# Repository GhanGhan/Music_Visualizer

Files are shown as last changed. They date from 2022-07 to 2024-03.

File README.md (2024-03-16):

# Overview      
The device receives an audio signal from a 3.5mm jack (i.e. a headphone jack) that is connected to any analog sound source. The audio signal is then separated into the **7 music frequency ranges** and their respective volumes' are then **displayed on 10 LED's using a decibel scale.**
The brightness of the LEDs and the maximum value of the decibal scale can be adjusted by the user by turning the potentiometers located at the bottom of the PCB shown in *Figure 1*!

Full_3D_View
***Figure 1: 3D View***
<!---
Hello world

<figure>
   <img src="https://github.com/GhanGhan/Music_Visualizer/assets/17633599/c1a8e4e7-99a0-4a1e-9c01-7bc1968a0fe4">
   <figcaption>**Figure 1: 3D View of Music Visualizer**</figcaption>
</figure>
--->

# Table of Contents
1. Summary of Functionaity
2. Operation Videos
3. Contained in Respository
4. Repository Structure
5. Folder & Design File Explanation
6. Generate Files for Fabrication
7. Current Issues
8. License
9. Acknowledgements

# Summary of Functionality
- Can change input source to a male or female jack using a slide switch as shown in *Figure 2*
- Can safely handle a differential input voltage signal of up to 32V
- Uses 6th order 60dB/decade active Butterworth filters to segment the signal into 7 spectrums
- Both the brightness of the LEDs and maximum scale voltage can be changed using logarithmic potentiometers
   - ** Due to how signal is processed by the filters, the maximum value of the volume scale is 3.5V
- 10 LEDS are used to display the volume of each spectrum as a percentage of the max value of the volume scale
   - 4 Blue LEDs     [4% : 12%]
   - 3 Yellow LEDS   [12% : 35%]
   - 3 Red LEDS      [35% : 100%]
Block Diagaram
***Figure 2: Block Diagaram of Signal, Power and Control Flow***

# Contained in Repository
- Spice design files (made using LTSpice)
- Schematic Capture and PCB layout (designed in KiCAD)
- Bill-of-Materials BOM
- Other important documents:
   - Sound characterization
   - Measured Frequency response
   - Docs related to properties of critical electrical components

# Operation Videos
Frequency_Sweep_Thumb25 (https://www.youtube.com/watch?v=qO5JhvR4XTk)
Capabilities_Thumb25 (https://www.youtube.com/watch?v=kU3bXjiCjgI)
Visualization_Thumb25 (https://www.youtube.com/watch?v=t0gG-SFj2FQ)

# Repository Structure
```
├── Documents
│   ├── BOM_Final.xlsx
│   ├── LED Driver IC.xlsx
│   ├── MaxIoOfEachFilterStage.xlsx
│   ├── Measured_Frequency_Response.xlsx
│   ├── Sound_Characterization.xlsx
│   └── Trace width vs current.xlsx
├── Schematic_PCB/Music_Visualizer
│   ├── Music_Visualizer-backups
│   ├── Project Library
│   │   ├── Coloured_LEDs
│   │   │   ├── LED D5 - Blue_cutted.step
│   │   │   ├── LED D5 - Red_cutted.step
│   │   │   └── LED D5 - Yellow_cutted.step
│   │   ├── DC_Power_Jack
│   │   │   ├── CUI_DEVICES_PJ-079BH.step
│   │   │   ├── CUI_DEVICES.kicad_mod
│   │   │   └── PJ-079BH.lib
│   │   ├── Female_Audio_Jack
│   │   │   └── SJ-3523-SMT-TR--3DModel-STEP-56544.step
│   │   ├── LM3915_LED_Driver
│   │   │   └── LM3915N-1.lib
│   │   ├── Linear_Voltage_Regulator
│   │   │   ├── DIP794W45P254L959H508Q8.kicad_mod
│   │   │   └── LT1054IPE4.step
│   │   ├── PTV09A_Pot_Vertical
│   │   │   ├── PTV09.kicad_mod
│   │   │   └── PTV09A-4225F-B104.step
│   │   ├── PW_On_Off_Switch
│   │   │   ├── E-SWITCH_RR511D1121.kicad_mod
│   │   │   └── RR511D1121.step
│   │   ├── Slide_Switch
│   │   │   ├── OS102011MS2QN1.step
│   │   │   └── SW_OS102011MS2QN1.kicad_mod
│   │   ├── License.txt
│   │   └── how-to-import.htm
│   ├── Music_Visualizer.csv
│   ├── Music_Visualizer.kicad_pcb
│   ├── Music_Visualizer.kicad_prl
│   ├── Music_Visualizer.kicad_pro
│   ├── Music_Visualizer.kicad_sch
│   ├── Music_Visualizer.wbk
│   ├── Music_Visualizer.xml
│   ├── Power.kicad_sch
│   ├── fp-info-cache
│   ├── fp-lib-table
│   └── sym-lib-table
└── Simulated Circuits
    ├── Entire_Circuit 
    │   ├── Full_Visualizer.asc
    │   └── LM324.txt
    ├── Filters_With_LED_Drivers
    │   ├── FinalBassFilterWithLEDDriver.asc
    │   ├── FinalBrillianceFilterWithLEDDriver.asc
    │   ├── FinalLowMidrangeWithLEDDriver.asc
    │   ├── FinalMidrangeFilterWithLEDDriver.asc
    │   ├── FinalPresenceFilterWithLEDDriver.asc
    │   ├── FinalSubBassFilterWithLEDDriver.asc
    │   ├── FinalUpperMidrangeFilterWithLEDDriver.asc
    │   └── LM324.txt
    ├── LED_Driving
    │   ├── LM3915_Base_Circuit.asc
    │   ├── LM3915_Chain.asc
    │   ├── RhiControl_LTC1250.asc
    │   └── Voltage_Follower_Replacement.asc
    ├── Power
    │   ├── LT1054_Inverter_and_regulator.asc
    │   └── Reverse_Voltage_Protection.asc
    └── Spectrum_Filters
        ├── Final_Filters
        │   ├── FinalBassFilterBuf.asc
        │   ├── FinalBrillianceFilterBuf.asc
        │   ├── FinalLowMidrangeBuf.asc
        │   ├── FinalMidrangeFilterBuf.asc
        │   ├── FinalPresenceFilterBuf.asc
        │   ├── FinalSubBassFilterBuf.asc
        │   ├── FinalUpperMidrangeFilterBuf.asc
        │   └── LM324.txt
        ├── Ideal_Filters
        │   ├── BassFilterSK.asc
        │   ├── BrillianceFilterSK.asc
        │   ├── LowMidrangeSK.asc
        │   ├── MidrangeFilterSK.asc
        │   ├── PresenceFilterSK.asc
        │   ├── SubBassFilterSK.asc
        │   └── UpperMidrangeFilterSK.asc
        └── JsonFiles
            ├── Bass Filter.asc
            ├── Brilliance Filter.asc
            ├── Low-Midrange.asc
            ├── Midrange Filter.asc
            ├── Presence Filter.asc
            ├── Sub-Bass Filter.asc
            └── Upper-MidrangeFilter.asc
  ```
# Folder & Design File Explanation
## Documents
- **BOM_Final:** The project Bill-Of-Materials (BOM)
   - Shows all the components that were used, the quantity of each, the prices, model number and where they were sourced from
- **LED Driver IC:** Comparison of the simulated characteristics and values found from breadboarding
- **MaxIoOfEachFilterStage:** Maximum possible current being output by each op-amp of each stage of every filter
- **Sound Characterization:** Shows voltages that were outputted from the audio jack the device was tested on, bandwidth and corner frequency of each spectrum, and steps of the volume-meter
## Schematic_PCB\Music Visualizer (KiCad Folder)
- **Project_Library:** Contains nesseccary .step files (3D models), .lib files (schematic symbols) and/or .kicad_mod files (PCB footprint)  of the DC power jack, female audio jack, LED driver, -5V Inverter & Regulator, potentiometer, On/Off rocker switch switch and slide switch.
    - If any of the file types for any of the circuit elements is not included in the associated sub-folder of the 'Project Library then it is provided by the programs 'Global Library'.
- **Music_Visualizer.kicad_pcb:** PCB layout file for the entire project.
- **Music_Visualizer.kicad_sch:** Main schematic layout file.
    - Contains all 7 frequency spectrums based on the spice files in Simulated_Circuits\Spectrum_Filter\Final_Filter folder.
    - Contains the Audio input circuit (male and female connections where a slide switch is used to choose one or the other), the mounting holes, and op amp bypass capacitors.
    - Contains the Power.kicad_sch and LED_driver.kicad_sch schematics as well
    - **Power.kicad_sch:** Contians circuit for the the +5V regulator, circuit to connect to external power supply with with reverse voltage protection  and -5V Inverter/Regulator as shown in *Figure 3*, the latter 2 are based on the spice files in Simulatd_Circuits\Power.
Power_Circuitry
***Figure 3: 9V & +/-5V Power Circuitry***

    - **Led_Driver.kicad_sch:** Contains the 7 LED drivers, LED brightness control and Rhi-Value Control Circuit based on the spice files in LED_Driving folder.
- **Music_Visualizer.kicad_pro:** Music Visualizer KiCad File.  When clicked it opens up a directory that allows you to access the PCB layout file and schematic layout file.
- Rest of the files are either self explanatory of support files for the KiCad program
## Simulated_Circuits
- **Entire Circuit\Full_Visualizer.asc:** A spice file that contains the 7 spectrum filters being driven by the input signal that contains a frequency from each of the spectrums.  Each of the filters is driving one of the ICs in the LM3915_Chain circuit.  Voltage dividers are used in place of potentiometers to model how turning their knobs allows for control of the LED brightness and scale of the volumeter.
    - **LM324.txt:** A text file that contains the 'macromodel' of the LM324 operational amplifier, allowing it to be used in spice files
- **Filters_With_LED_Drivers:** Contains a spice file for every spectrum filter that driving an LM3915_Base_Circuit.  Also contains an LM324.txt file.
- **LED_Driving:**
    - **LM3915_Base_Circuit.asc:** Contains an LM3915 (the led driver) IC connected to 10 LEDs as shown in *Figure 4*.  The IC is driven by a sinusoidal voltage source.  **Vref (Current reference pin)** is used to set the diode current to about 18mA using a grounded 674 ohm resistor.  It is powered by 9V, and **Vrhi (high-input reference-voltage)** is set to 3.5V.
Base_DriverV2
***Figure 4: LED Driving Circuit Prototype***

    - **LM3915_Chain.asc:** Contains 7 LM3915_Base circuits all driven by the same input AC voltage and high-input reference voltage.  Instead of ground, the 674 ohm resistor of each LM3915_Base circuit is connected to a grounded 10kohm potentiometer.  Changing the resistance of the potentiometer allows one to adjust the current going through the LEDs of all of the LED drivers.
    - **RhiControl_LTC1250.asc:** Connects to the high-input reference voltage pin (*Rhi in Figure 4*) of the LED driver IC as shown in *Figure 5*.  R1 and R2 act as a potentiometer. A voltage follower is appended to the ouput of the 'potentiometer' because the average load voltage of the Vrhi pin is about 17.5kohm, when there are in parallel the equivalent reisistance is about 2.5kohm.  The voltage follower ensures that the voltage at the pins is is the same value as the output of the potentiometer.  This particular op-amp was chosen because it has a max input offset voltage of < |10uV|, this means that the voltage at the pin will always be within 10uV of the desired voltage.
RhiControl_LTC1250_Enlarged
***Figure 5: Volume Scale Range Control Circuit***
  
    - **Voltage_Follower_Replacement.asc:**  This is a common-collector circuit, a single transistor implementation of a current follower.  The 2N2222 transistor is used to replace the LTC1250 op-amp because it shorted the -5 and +5 terminals that it was being powered from.
- **Spectrum_Filters:**
    - **Final_Filters:** Folder contains the final filter design for the 7 spectrum filters; Sub-Bass, Bass, Low-Midrange, Midrange, Upper-Midrange, Presence and Brilliance.  Each filter is prepended with a voltage buffer to isolate themselves from the signal source.  This way the impedances of the filters do not affect each other.  Each filter also has a high-pass filter appended to it to prevent unintented activation of the LED driver due to the input-offset voltage of the LM324 op amps which can be as high as 7mV.  *Figure 6* displays the Sub-Bass filters, all of the spectrum filters have the same topology.
  SubBaseFinalFilter
***Figure 6: Complete Sub-Base Filter**

         - Also the resistor values in the final design are slightly different from the "ideal version".  This is because those resistances need at least two resistors in series or parallel to be realized.  The nominal resistor values choses for the final design are within 1.5% of the ideal value.  It was determined that this did not have a significant effect on the frequency response. 
    - **Ideal_Filters:** Folder contains design for idealized implementation of the 7 spectrum filters.  In these LTSpice files ideal op-amps are being used and all of the resistor values match the values provided from the Analog Filter Wizard.
    - **JsonFiles:** The spectrum filters were designed using Analog Devices 'Analog Filter Wizard'.  Once you've inputted the specifications "Passband gain, corner frequency, bandwidth, stopband, center frequency, stages etc."  These are the saved specification files of the Analog filter Wizard for each filter.
         - The center frequency saved in these files are different from the actual center frequency of the filters because (for unidentified reasons) when the correct center frequency was inputted to wrong corner frequencies were outputed.  The center frequency contained in these files gives filters with the correct corner frequencies.

# Generate Files for Fabrication
- If you want to generate the Gerber and Drill files so that the project can be fabricated by a JLCPCB, follow the steps of this website: https://jlcpcb.com/help/article/16-How-to-generate-Gerber-and-Drill-files-in-KiCad-6

# Current Issues
- The last stage of the sub-bass filter generates a power 343Hz wave on its own that is so powerful it activates all of the associated LEDS.  
- The LT1054 op amp shorts the +5 and -5 power rails together and destroys itself in the process.  The is why it was replaced with a Common Collector circuit.

# License
- 
- This project is licensed under the [Creative Commons Attribution 3.0 Unported License](https://creativecommons.org/licenses/by/3.0/).
  
# Acknoledgments
- I would like to thank Snap EDA for providing me with the necessary step, kicad_mod and lib files.
- I would like to thank the YouTube Channel "Phil's Lab" for making videos that allowed me to easily learn to use KiCad 6.

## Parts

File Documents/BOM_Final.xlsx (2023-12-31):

Comment | Designator | Footprint | Quantity | Digi-Key PN | MPN | Price | Total Price | Part Page
47n | C1,C2 | Capacitor_SMD:C_0603_1608Metric_Pad1.08x0.95mm_HandSolder | 2 | 1292-1445-1-ND | 0603B473J250CT | $0.10 | $0.20 | https://www.digikey.ca/en/products/detail/walsin-technology-corporation/0603B473J250CT/9354942
24n | C11,C12 | Capacitor_SMD:C_0805_2012Metric | 2 | 478-10432-1-ND | 08051C243JAT2A | $0.43 | $0.86 | https://www.digikey.ca/en/products/detail/kyocera-avx/08051C243JAT2A/1601378
4.7n | C13,C14 | Capacitor_SMD:C_0603_1608Metric_Pad1.08x0.95mm_HandSolder | 2 | 1292-1440-1-ND | 0603B472J500CT | $0.10 | $0.20 | https://www.digikey.ca/en/products/detail/walsin-technology-corporation/0603B472J500CT/9354937
3.3n | C15,C16 | Capacitor_SMD:C_0603_1608Metric_Pad1.08x0.95mm_HandSolder | 2 | 1292-1521-1-ND | 0603N332J500CT | $0.10 | $0.20 | https://www.digikey.ca/en/products/detail/walsin-technology-corporation/0603N332J500CT/9355018
6.2n | C17,C18 | Capacitor_SMD:C_0805_2012Metric | 2 | 490-1637-1-ND | GRM2195C1H622JA01D | $0.41 | $0.82 | https://www.digikey.ca/en/products/detail/murata-electronics/GRM2195C1H622JA01D/586784
1.6n | C19,C20 | Capacitor_SMD:C_0603_1608Metric_Pad1.08x0.95mm_HandSolder | 2 | 490-1456-1-ND | GRM1885C1H162JA01D | $0.18 | $0.36 | https://www.digikey.ca/en/products/detail/murata-electronics/GRM1885C1H162JA01D/586948
1n | C21,C22,C25,C26,C27,C28,C29,C30,C31,C32,C33,C34,C35,C36,C37,C38,C41,C42 | Capacitor_SMD:C_0603_1608Metric_Pad1.08x0.95mm_HandSolder | 18 | 1276-1091-1-ND | CL10C102JB8NNNC | $0.10 | $1.80 | https://www.digikey.ca/en/products/detail/samsung-electro-mechanics/CL10C102JB8NNNC/3886749
3n | C23,C24 | Capacitor_SMD:C_0603_1608Metric_Pad1.08x0.95mm_HandSolder | 2 | 490-6384-1-ND | GRM1885C1H302JA01D | $0.11 | $0.22 | https://www.digikey.ca/en/products/detail/murata-electronics/GRM1885C1H302JA01D/2611152
27n | C3,C4 | Capacitor_SMD:C_0603_1608Metric_Pad1.08x0.95mm_HandSolder | 2 | 478-KAF15AR71H273JMTR-ND | KAF15AR71H273JM | $0.18 | $0.36 | https://www.digikey.ca/en/products/detail/kyocera-avx/KAF15AR71H273JM/3660870
820p | C39,C40 | Capacitor_SMD:C_0603_1608Metric_Pad1.08x0.95mm_HandSolder | 2 | 1292-1548-1-ND | 0603N821J500CT | $0.14 | $0.28 | https://www.digikey.ca/en/products/detail/walsin-technology-corporation/0603N821J500CT/9355045
100u | C43,C44 | Capacitor_SMD:C_1206_3216Metric | 2 | 490-GRM31CD80J107MEA8KCT-ND | GRM31CD80J107MEA8K | $0.56 | $1.12 | https://www.digikey.ca/en/products/detail/murata-electronics/GRM31CD80J107MEA8K/13905021
10u | C45,C46,C54 | Capacitor_SMD:C_0805_2012Metric | 3 | 1276-1096-1-ND | CL21A106KOQNNNE | $0.14 | $0.42 | https://www.digikey.ca/en/products/detail/samsung-electro-mechanics/CL21A106KOQNNNE/3886754
1u | C47,C48,C49,C52,C53,C57,C58 | Capacitor_SMD:C_0603_1608Metric_Pad1.08x0.95mm_HandSolder | 7 | 311-3485-1-ND | CC0603JRX7R7BB105 | $0.34 | $2.38 | https://www.digikey.ca/en/products/detail/yageo/CC0603JRX7R7BB105/7164369
75n | C5,C6 | Capacitor_SMD:C_1206_3216Metric | 2 | 490-6506-1-ND | GRM31C5C1H753JA01L | $0.53 | $1.06 | https://www.digikey.ca/en/products/detail/murata-electronics/GRM31C5C1H753JA01L/2548145
0.33uF | C50 | Capacitor_SMD:C_0603_1608Metric_Pad1.08x0.95mm_HandSolder | 1 | 732-7992-1-ND | 885012206074 | $0.14 | $0.14 | https://www.digikey.ca/en/products/detail/w%C3%BCrth-elektronik/885012206074/5453847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
100u | C55 | Capacitor_THT:C_Radial_D5.0mm_H5.0mm_P2.00mm | 1 | 732-8598-1-ND | 860010372006 | $0.15 | $0.15 | https://www.digikey.ca/en/products/detail/w%C3%BCrth-elektronik/860010372006/5726847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
0.002u | C56 | Capacitor_SMD:C_0603_1608Metric_Pad1.08x0.95mm_HandSolder | 1 | 490-GCM1885C1H202JA16DCT-ND | GCM1885C1H202JA16D | $0.10 | $0.10 | https://www.digikey.ca/en/products/detail/murata-electronics/GCM1885C1H202JA16D/2591452
10u | C59 | Capacitor_THT:CP_Radial_D5.0mm_P2.00mm | 1 | 732-8593-1-ND | 860010372001 | $0.14 | $0.14 | https://www.digikey.ca/en/products/detail/w%C3%BCrth-elektronik/860010372001/5726842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
0.1uF | C51,C60,C61,C62,C63,C64,C65,C66,C67,C68,C69,C70,C71,C72,C73 | Capacitor_SMD:C_0805_2012Metric | 15 | 1276-1099-1-ND | CL21B104KACNNNC | $0.14 | $2.10 | https://www.digikey.ca/en/products/detail/samsung-electro-mechanics/CL21B104KACNNNC/3886757
13n | C7,C8 | Capacitor_SMD:C_0805_2012Metric | 2 | 490-12752-1-ND | GRM2195C1H133JA01D | $0.36 | $0.72 | https://www.digikey.ca/en/products/detail/murata-electronics/GRM2195C1H133JA01D/2545205
6.8n | C9,C10 | Capacitor_SMD:C_0805_2012Metric | 2 | 399-C0805C682J5GEC7210CT-ND | C0805C682J5GEC7210 | $0.36 | $0.72 | https://www.digikey.ca/en/products/detail/kemet/C0805C682J5GEC7210/8645965
LED | D1,D2,D3,D4,D5,D6,D7,D8,D9,D10,D11,D12,D13,D14,D15,D16,D17,D18,D19,D20,D21,D22,D23,D24,D25,D26,D27,D28,D29,D30,D31,D32,D33,D34,D35,D36,D37,D38,D39,D40,D41,D42,D43,D44,D45,D46,D47,D48,D49,D50,D51,D52,D53,D54,D55,D56,D57,D58,D59,D60,D61,D62,D63,D64,D65,D66,D67,D68,D69,D70,D71 | LED_THT:LED_D5.0mm | 70 | N/A | N/A | $0.03 | $2.32 | https://www.amazon.ca/gp/product/B07N2GVCYZ/ref=ppx_yo_dt_b_search_asin_title?ie=UTF8&th=1
MountingHole | H1,H2,H3,H4 | MountingHole:MountingHole_3.2mm_M3 | 4 | N/A | N/A | N/A | 0 | N/A
AudioJack3 | J1 | Connector_Audio:Jack_3.5mm_CUI_SJ-3523-SMT_Horizontal | 1 | CP-3523SJCT-ND | SJ-3523-SMT-TR | $1.42 | $1.42 | https://www.digikey.ca/en/products/detail/cui-devices/SJ-3523-SMT-TR/281297
PJ-079BH | J2 | CUI_PJ-079BH | 1 | 102-5547-ND | PJ-079BH | $2.19 | $2.19 | https://www.digikey.ca/en/products/detail/cui-devices/PJ-079BH/9830149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
Screw_Terminal_01x02 | J3 | TerminalBlock_Phoenix:TerminalBlock_Phoenix_MPT-0,5-2-2.54_1x02_P2.54mm_Horizontal | 1 | 952-2262-ND | M20-9990246 | $0.19 | $0.19 | https://www.digikey.ca/en/products/detail/harwin-inc/M20-9990246/3728226?s=N4IgTCBcDaILJgAwFoCc7FgCwDYQF0BfIA
Jumper_2_Open | JP2 | Connector_PinHeader_2.54mm:PinHeader_2x01_P2.54mm_Vertical | 1 | DMP2123LQ-7DICT-ND | DMP2123LQ-7 | $0.80 | $0.80 | https://www.digikey.ca/en/products/detail/diodes-incorporated/DMP2123LQ-7/5768836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
DMP2123LQ-7 | Q1 | Package_TO_SOT_SMD:SOT-23 | 1 | DMP2123LQ-7DICT-ND | DMP2123LQ-7 | $0.69 | $0.69 | https://www.digikey.ca/en/products/detail/diodes-incorporated/DMP2123LQ-7/5768836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
84.5k | R1 | Resistor_SMD:R_0603_1608Metric_Pad0.98x0.95mm_HandSolder | 1 | 311-84.5KHRCT-ND | RC0603FR-0784K5L | $0.15 | $0.15 | https://www.digikey.ca/en/products/detail/yageo/RC0603FR-0784K5L/727408
110k | R10 | Resistor_SMD:R_0603_1608Metric_Pad0.98x0.95mm_HandSolder | 1 | 311-110KHRCT-ND | RC0603FR-07110KL | $0.15 | $0.15 | https://www.digikey.ca/en/products/detail/yageo/RC0603FR-07110KL/726905
162k | R12 | Resistor_SMD:R_0603_1608Metric_Pad0.98x0.95mm_HandSolder | 1 | 311-162KHRCT-ND | RC0603FR-07162KL | $0.15 | $0.15 | https://www.digikey.ca/en/products/detail/yageo/RC0603FR-07162KL/726975
118k | R13 | Resistor_SMD:R_0603_1608Metric_Pad0.98x0.95mm_HandSolder | 1 | 311-118KHRCT-ND | RC0603FR-07118KL | $0.15 | $0.15 | https://www.digikey.ca/en/products/detail/yageo/RC0603FR-07118KL/726911
63.4k | R14 | Resistor_SMD:R_0603_1608Metric_Pad0.98x0.95mm_HandSolder | 1 | 311-63.4KHRCT-ND | RC0603FR-0763K4L | $0.15 | $0.15 | https://www.digikey.ca/en/products/detail/yageo/RC0603FR-0763K4L/727340
62k | R15 | Resistor_SMD:R_0603_1608Metric_Pad0.98x0.95mm_HandSolder | 1 | 311-62.0KHRCT-ND | RC0603FR-0762KL | $0.15 | $0.15 | https://www.digikey.ca/en/products/detail/yageo/RC0603FR-0762KL/727336
309k | R16 | Resistor_SMD:R_0603_1608Metric_Pad0.98x0.95mm_HandSolder | 1 | 311-309KHRCT-ND | RC0603FR-07309KL | $0.15 | $0.15 | https://www.digikey.ca/en/products/detail/yageo/RC0603FR-07309KL/727149
68k | R17 | Resistor_SMD:R_0603_1608Metric_Pad0.98x0.95mm_HandSolder | 1 | 311-68.0KHRCT-ND | RC0603FR-0768KL | $0.15 | $0.15 | https://www.digikey.ca/en/products/detail/yageo/RC0603FR-0768KL/727352
66.5k | R18,R31,R36,R51 | Resistor_SMD:R_0603_1608Metric_Pad0.98x0.95mm_HandSolder | 1 | 311-66.5KHRCT-ND | RC0603FR-0766K5L | $0.15 | $0.15 | https://www.digikey.ca/en/products/detail/yageo/RC0603FR-0766K5L/727348
332k | R19 | Resistor_SMD:R_0603_1608Metric_Pad0.98x0.95mm_HandSolder | 1 | 311-332KHRCT-ND | RC0603FR-07332KL | $0.15 | $0.15 | https://www.digikey.ca/en/products/detail/yageo/RC0603FR-07332KL/727165
160k | R2,R41,R50 | Resistor_SMD:R_0603_1608Metric_Pad0.98x0.95mm_HandSolder | 1 | 311-160KHRCT-ND | RC0603FR-07160KL | $0.15 | $0.15 | https://www.digikey.ca/en/products/detail/yageo/RC0603FR-07160KL/726973
137k | R20 | Resistor_SMD:R_0603_1608Metric_Pad0.98x0.95mm_HandSolder | 1 | 311-137KHRCT-ND | RC0603FR-07137KL | $0.15 | $0.15 | https://www.digikey.ca/en/products/detail/yageo/RC0603FR-07137KL/726939
45.3k | R21 | Resistor_SMD:R_0603_1608Metric_Pad0.98x0.95mm_HandSolder | 1 | 311-45.3KHRCT-ND | RC0603FR-0745K3L | $0.15 | $0.15 | https://www.digikey.ca/en/products/detail/yageo/RC0603FR-0745K3L/727245
270k | R22,R35,R53 | Resistor_SMD:R_0603_1608Metric_Pad0.98x0.95mm_HandSolder | 1 | 311-270KHRCT-ND | RC0603FR-07270KL | $0.15 | $0.15 | https://www.digikey.ca/en/products/detail/yageo/RC0603FR-07270KL/727104
143k | R23 | Resistor_SMD:R_0603_1608Metric_Pad0.98x0.95mm_HandSolder | 1 | RMCF0603FT143KCT-ND | RMCF0603FT143K | $0.15 | $0.15 | https://www.digikey.ca/en/products/detail/stackpole-electronics-inc/RMCF0603FT143K/1761301
19.1k | R24 | Resistor_SMD:R_0603_1608Metric_Pad0.98x0.95mm_HandSolder | 1 | 311-19.1KHRCT-ND | RC0603FR-0719K1L | $0.15 | $0.15 | https://www.digikey.ca/en/products/detail/yageo/RC0603FR-0719K1L/727001
590k | R25 | Resistor_SMD:R_0603_1608Metric_Pad0.98x0.95mm_HandSolder | 1 | 311-590KHRCT-ND | RC0603FR-07590KL | $0.15 | $0.15 | https://www.digikey.ca/en/products/detail/yageo/RC0603FR-07590KL/727315
140k | R26 | Resistor_SMD:R_0603_1608Metric_Pad0.98x0.95mm_HandSolder | 1 | 311-140KHRCT-ND | RC0603FR-07140KL | $0.15 | $0.15 | https://www.digikey.ca/en/products/detail/yageo/RC0603FR-07140KL/726947
18.7k | R27 | Resistor_SMD:R_0603_1608Metric_Pad0.98x0.95mm_HandSolder | 1 | 311-18.7KHRCT-ND | RC0603FR-0718K7L | $0.15 | $0.15 | https://www.digikey.ca/en/products/detail/yageo/RC0603FR-0718K7L/726993
576k | R28 | Resistor_SMD:R_0603_1608Metric_Pad0.98x0.95mm_HandSolder | 1 | 311-576KHRCT-ND | RC0603FR-07576KL | $0.15 | $0.15 | https://www.digikey.ca/en/products/detail/yageo/RC0603FR-07576KL/727311
100k | R29,R30 | Resistor_SMD:R_0603_1608Metric_Pad0.98x0.95mm_HandSolder | 1 | 311-100KHRCT-ND | RC0603FR-07100KL | $0.15 | $0.15 | https://www.digikey.ca/en/products/detail/yageo/RC0603FR-07100KL/726889
169k | R3 | Resistor_SMD:R_0603_1608Metric_Pad0.98x0.95mm_HandSolder | 1 | 311-169KHRCT-ND | RC0603FR-07169KL | $0.15 | $0.15 | https://www.digikey.ca/en/products/detail/yageo/RC0603FR-07169KL/726979
33.2k | R32 | Resistor_SMD:R_0603_1608Metric_Pad0.98x0.95mm_HandSolder | 1 | 311-33.2HRCT-ND | RC0603FR-0733R2L | $0.15 | $0.15 | https://www.digikey.ca/en/products/detail/yageo/RC0603FR-0733R2L/727160
56k | R33 | Resistor_SMD:R_0603_1608Metric_Pad0.98x0.95mm_HandSolder | 1 | 13-RC0603FR-1356KLCT-ND | RC0603FR-1356KL | $0.15 | $0.15 | https://www.digikey.ca/en/products/detail/yageo/RC0603FR-1356KL/14286513
48.7k | R34,R58 | Resistor_SMD:R_0603_1608Metric_Pad0.98x0.95mm_HandSolder | 1 | 311-48.7KHRCT-ND | RC0603FR-0748K7L | $0.15 | $0.15 | https://www.digikey.ca/en/products/detail/yageo/RC0603FR-0748K7L/727261
57.6k | R37 | Resistor_SMD:R_0603_1608Metric_Pad0.98x0.95mm_HandSolder | 1 | 311-57.6KHRCT-ND | RC0603FR-0757K6L | $0.15 | $0.15 | https://www.digikey.ca/en/products/detail/yageo/RC0603FR-0757K6L/727309
324k | R38 | Resistor_SMD:R_0603_1608Metric_Pad0.98x0.95mm_HandSolder | 1 | 311-324KHRCT-ND | RC0603FR-07324KL | $0.15 | $0.15 | https://www.digikey.ca/en/products/detail/yageo/RC0603FR-07324KL/727157
78.7k | R39,R48 | Resistor_SMD:R_0603_1608Metric_Pad0.98x0.95mm_HandSolder | 1 | 311-78.7KHRCT-ND | RC0603FR-0778K7L | $0.15 | $0.15 | https://www.digikey.ca/en/products/detail/yageo/RC0603FR-0778K7L/727386
90.9k | R4,R11,R65 | Resistor_SMD:R_0603_1608Metric_Pad0.98x0.95mm_HandSolder | 1 | 311-90.9KHRCT-ND | RC0603FR-0790K9L | $0.15 | $0.15 | https://www.digikey.ca/en/products/detail/yageo/RC0603FR-0790K9L/727424
26.7k | R40 | Resistor_SMD:R_0603_1608Metric_Pad0.98x0.95mm_HandSolder | 1 | 311-26.7KHRCT-ND | RC0603FR-0726K7L | $0.15 | $0.15 | https://www.digikey.ca/en/products/detail/yageo/RC0603FR-0726K7L/727094
59k | R42 | Resistor_SMD:R_0603_1608Metric_Pad0.98x0.95mm_HandSolder | 1 | 311-59.0KHRCT-ND | RC0603FR-0759KL | $0.15 | $0.15 | https://www.digikey.ca/en/products/detail/yageo/RC0603FR-0759KL/727313
7.87k | R43 | Resistor_SMD:R_0603_1608Metric_Pad0.98x0.95mm_HandSolder | 1 | 311-7.87KHRCT-ND | RC0603FR-077K87L | $0.15 | $0.15 | https://www.digikey.ca/en/products/detail/yageo/RC0603FR-077K87L/727368
243k | R44 | Resistor_SMD:R_0603_1608Metric_Pad0.98x0.95mm_HandSolder | 1 | 311-243KHRCT-ND | RC0603FR-07243KL | $0.15 | $0.15 | https://www.digikey.ca/en/products/detail/yageo/RC0603FR-07243KL/727084
107k | R45 | Resistor_SMD:R_0603_1608Metric_Pad0.98x0.95mm_HandSolder | 1 | 311-107KHRCT-ND | RC0603FR-07107KL | $0.15 | $0.15 | https://www.digikey.ca/en/products/detail/yageo/RC0603FR-07107KL/726895
14.7k | R46 | Resistor_SMD:R_0603_1608Metric_Pad0.98x0.95mm_HandSolder | 1 | 311-14.7KHRCT-ND | RC0603FR-0714K7L | $0.15 | $0.15 | https://www.digikey.ca/en/products/detail/yageo/RC0603FR-0714K7L/726945
453k | R47 | Resistor_SMD:R_0603_1608Metric_Pad0.98x0.95mm_HandSolder | 1 | 311-453KHRCT-ND | RC0603FR-07453KL | $0.15 | $0.15 | https://www.digikey.ca/en/products/detail/yageo/RC0603FR-07453KL/727247
7.32k | R49 | Resistor_SMD:R_0603_1608Metric_Pad0.98x0.95mm_HandSolder | 1 | 311-7.32KHRCT-ND | RC0603FR-077K32L | $0.15 | $0.15 | https://www.digikey.ca/en/products/detail/yageo/RC0603FR-077K32L/727364
37.4k | R5,R62 | Resistor_SMD:R_0603_1608Metric_Pad0.98x0.95mm_HandSolder | 1 | 311-37.4KHRCT-ND | RC0603FR-0737K4L | $0.15 | $0.15 | https://www.digikey.ca/en/products/detail/yageo/RC0603FR-0737K4L/727187
2.87k | R52 | Resistor_SMD:R_0603_1608Metric_Pad0.98x0.95mm_HandSolder | 1 | 311-2.87KHRCT-ND | RC0603FR-072K87L | $0.15 | $0.15 | https://www.digikey.ca/en/products/detail/yageo/RC0603FR-072K87L/727036
95.3k | R54 | Resistor_SMD:R_0603_1608Metric_Pad0.98x0.95mm_HandSolder | 1 | 311-95.3KHRCT-ND | RC0603FR-0795K3L | $0.15 | $0.15 | https://www.digikey.ca/en/products/detail/yageo/RC0603FR-0795K3L/727436
4.02k | R55 | Resistor_SMD:R_0603_1608Metric_Pad0.98x0.95mm_HandSolder | 1 | 311-4.02KHRCT-ND | RC0603FR-074K02L | $0.15 | $0.15 | https://www.digikey.ca/en/products/detail/yageo/RC0603FR-074K02L/727203
383k | R56 | Resistor_SMD:R_0603_1608Metric_Pad0.98x0.95mm_HandSolder | 1 | 311-383KHRCT-ND | RC0603FR-07383KL | $0.15 | $0.15 | https://www.digikey.ca/en/products/detail/yageo/RC0603FR-07383KL/727193
11.5k | R57 | Resistor_SMD:R_0805_2012Metric | 1 | 311-11.5KCRCT-ND | RC0805FR-0711K5L | $0.15 | $0.15 | https://www.digikey.ca/en/products/detail/yageo/RC0805FR-0711K5L/727556
22.6k | R59 | Resistor_SMD:R_0603_1608Metric_Pad0.98x0.95mm_HandSolder | 1 | 311-22.6KHRCT-ND | RC0603FR-0722K6L | $0.15 | $0.15 | https://www.digikey.ca/en/products/detail/yageo/RC0603FR-0722K6L/727060
402k | R6 | Resistor_SMD:R_0603_1608Metric_Pad0.98x0.95mm_HandSolder | 1 | 311-402KHRCT-ND | RC0603FR-07402KL | $0.15 | $0.15 | https://www.digikey.ca/en/products/detail/yageo/RC0603FR-07402KL/727223
8.06k | R60 | Resistor_SMD:R_0603_1608Metric_Pad0.98x0.95mm_HandSolder | 1 | 311-8.06KHRCT-ND | RC0603FR-078K06L | $0.15 | $0.15 | https://www.digikey.ca/en/products/detail/yageo/RC0603FR-078K06L/727389
4.32k | R61 | Resistor_SMD:R_0603_1608Metric_Pad0.98x0.95mm_HandSolder | 1 | 311-4.32KHRCT-ND | RC0603FR-074K32L | $0.15 | $0.15 | https://www.digikey.ca/en/products/detail/yageo/RC0603FR-074K32L/727207
19.6k | R63 | Resistor_SMD:R_0603_1608Metric_Pad0.98x0.95mm_HandSolder | 1 | 311-19.6KHRCT-ND | RC0603FR-0719K6L | $0.15 | $0.15 | https://www.digikey.ca/en/products/detail/yageo/RC0603FR-0719K6L/727003
10.7k | R64 | Resistor_SMD:R_0603_1608Metric_Pad0.98x0.95mm_HandSolder | 1 | 311-10.7KHRCT-ND | RC0603FR-0710K7L | $0.15 | $0.15 | https://www.digikey.ca/en/products/detail/yageo/RC0603FR-0710K7L/726887
1k | R66,R67,R68,R69,R70,R71,R72 | Resistor_SMD:R_0603_1608Metric_Pad0.98x0.95mm_HandSolder | 1 | RNCP0603FTD1K00CT-ND | RNCP0603FTD1K00 | $0.15 | $0.15 | https://www.digikey.ca/en/products/detail/stackpole-electronics-inc/RNCP0603FTD1K00/2240106
86.6k | R7 | Resistor_SMD:R_0603_1608Metric_Pad0.98x0.95mm_HandSolder | 1 | YAG3330CT-ND | RC0603FR-0786R6L | $0.15 | $0.15 | https://www.digikey.ca/en/products/detail/yageo/RC0603FR-0786R6L/5281190
20k | R73 | Resistor_SMD:R_0603_1608Metric_Pad0.98x0.95mm_HandSolder | 1 | 311-20.0KHRCT-ND | RC0603FR-0720KL | $0.15 | $0.15 | https://www.digikey.ca/en/products/detail/yageo/RC0603FR-0720KL/727040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
102k | R74 | Resistor_SMD:R_0603_1608Metric_Pad0.98x0.95mm_HandSolder | 1 | 311-102KHRCT-ND | RC0603FR-07102KL | $0.15 | $0.15 | https://www.digikey.ca/en/products/detail/yageo/RC0603FR-07102KL/726891
680 | R75,R76,R77,R78,R79,R80,R81 | Resistor_SMD:R_0603_1608Metric_Pad0.98x0.95mm_HandSolder | 1 | 311-680HRCT-ND | RC0603FR-07680RL | $0.15 | $0.15 | https://www.digikey.ca/en/products/detail/yageo/RC0603FR-07680RL/727355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
35.7k | R8 | Resistor_SMD:R_0603_1608Metric_Pad0.98x0.95mm_HandSolder | 1 | 311-35.7KHRCT-ND | RC0603FR-0735K7L | $0.15 | $0.15 | https://www.digikey.ca/en/products/detail/yageo/RC0603FR-0735K7L/727175
620 | R82 | Resistor_SMD:R_0603_1608Metric_Pad0.98x0.95mm_HandSolder | 1 | P620BYCT-ND | ERJ-PA3F6200V | $0.19 | $0.19 | https://www.digikey.ca/en/products/detail/panasonic-electronic-components/ERJ-PA3F6200V/5035943
390k | R9 | Resistor_SMD:R_0603_1608Metric_Pad0.98x0.95mm_HandSolder | 1 | 311-390KHRCT-ND | RC0603FR-07390KL | $0.15 | $0.15 | https://www.digikey.ca/en/products/detail/yageo/RC0603FR-07390KL/727199
10k_LED_Brightness_Pot | RV1 | PTV09A_Pot_Vertical:PTV09 | 1 | PTV09A-4020F-A103-ND | PTV09A-4020F-A103 | $1.45 | $1.45 | https://www.digikey.ca/en/products/detail/bourns-inc/PTV09A-4020F-A103/3781119
5k_Rhi_Adjuster | RV2 | PTV09A_Pot_Vertical:PTV09 | 1 | PTV09A-4020F-A502-ND | PTV09A-4020F-A502 | $1.45 | $1.45 | https://www.digikey.ca/en/products/detail/bourns-inc/PTV09A-4020F-A502/3781121
SW_SPDT | SW1 | Slide_Switch:SW_OS102011MS2QN1 | 1 | CKN9565-ND | OS102011MS2QN1 | $0.87 | $0.87 | https://www.digikey.ca/en/products/detail/c-k/OS102011MS2QN1/411602
SW_SPST | SW2 | PW_On_Off_Switch:E-SWITCH_RR511D1121 | 1 | EG4777-ND | RR511D1121 | $1.66 | $1.66 | https://www.digikey.ca/en/products/detail/e-switch/RR511D1121/2116256?s=N4IgTCBcDaIEpwKwEZkBFVmSAugXyA
LM324 | U1,U2,U3,U4,U5,U6,U7 | Package_SO:SOIC-14_3.9x8.7mm_P1.27mm | 7 | 296-14597-1-ND | LM324DR | $0.55 | $3.85 | https://www.digikey.ca/en/products/detail/texas-instruments/LM324DR/555719
LM3915N-1 | U10,U11,U12,U13,U14,U15,U16 | Package_DIP:DIP-18_W7.62mm_Socket | 7 | N/A | N/A | $2.26 | $15.83 | https://www.amazon.ca/gp/product/B0839884KH/ref=ppx_yo_dt_b_asin_title_o00_s00?ie=UTF8&psc=1
NCP161ASN350T1G | U17 | Package_TO_SOT_SMD:SOT-23-5 | 1 | 488-NCP161ASN350T1GCT-ND | NCP161ASN350T1G | $0.81 | $0.81 | https://www.digikey.ca/en/products/detail/onsemi/NCP161ASN350T1G/10064813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
NCS333ASQ3T2G | U18 | Package_TO_SOT_SMD:SOT-353_SC-70-5 | 1 | NCS333ASQ3T2GOSCT-ND | NCS333ASQ3T2G | $1.02 | $1.02 | https://www.digikey.ca/en/products/detail/onsemi/NCS333ASQ3T2G/8636491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
LT1054 | U8 | LT1054_PDIP_Lin_Reg:DIP794W45P254L959H508Q8 | 1 | 296-9591-5-ND | LT1054CP | $5.00 | $5.00 | https://www.digikey.ca/en/products/detail/texas-instruments/LT1054CP/379779
MC78L05_TO92 | U9 | Package_TO_SOT_THT:TO-92_Inline | 1 | MC78L05ACPRMGOSCT-ND | MC78L05ACPRMG | $0.85 | $0.85 | https://www.digikey.ca/en/products/detail/onsemi/MC78L05ACPRMG/1481329
 |  |  |  |  |  |  | $63.35
 |  | ***The LEDS and LM3915 IC could not be bought as individual components
 |  | The LEDs came in a pack of 500 | actual cost | 16.59
 |  | The LM3915 IC came in a pack of 10 | actual cost | 22.62
 |  | The True total cost of the parts for the project | $84.40

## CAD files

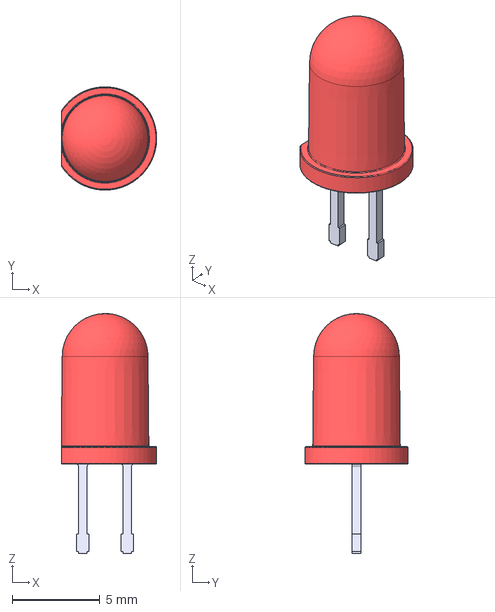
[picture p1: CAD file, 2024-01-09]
Schematic_PCB/Music_Visualizer/Project_Library/Coloured_LEDs/LED D5 - Red_cutted.step
5.45 x 5.90 x 13.7 mm

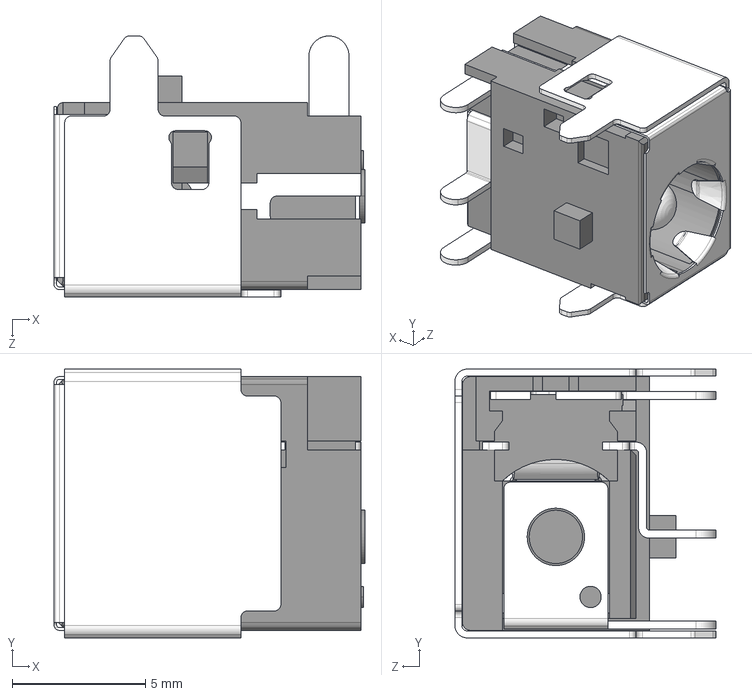
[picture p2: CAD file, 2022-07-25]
Schematic_PCB/Music_Visualizer/Project_Library/DC_Power_Jack/CUI_DEVICES_PJ-079BH.step
11.6 x 10.1 x 9.78 mm

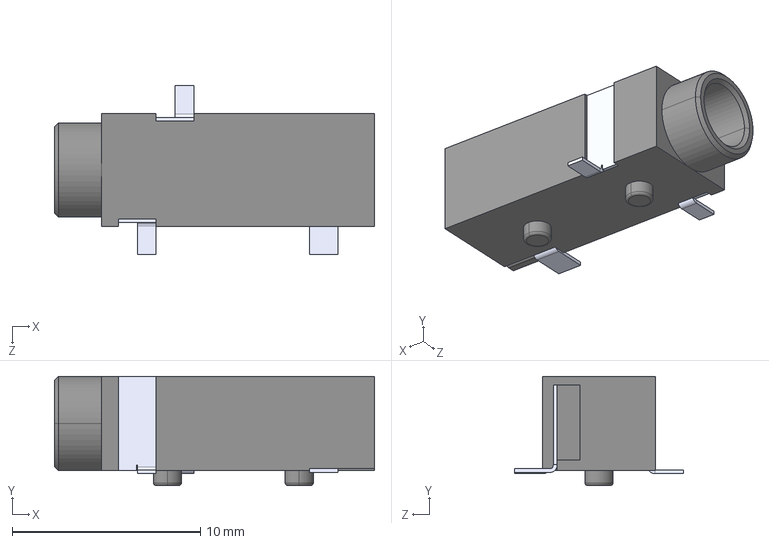
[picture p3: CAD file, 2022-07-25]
Schematic_PCB/Music_Visualizer/Project_Library/Female_Audio_Jack/SJ-3523-SMT-TR--3DModel-STEP-56544.STEP
17.0 x 5.80 x 9.00 mm

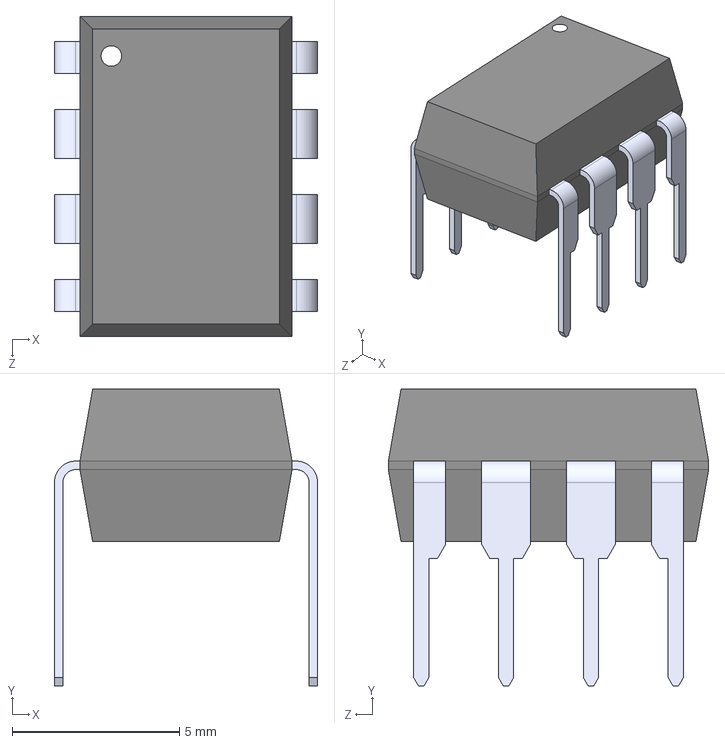
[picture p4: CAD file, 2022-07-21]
Schematic_PCB/Music_Visualizer/Project_Library/Linear_Voltage_Regulator/LT1054IPE4.step
7.87 x 8.89 x 9.59 mm

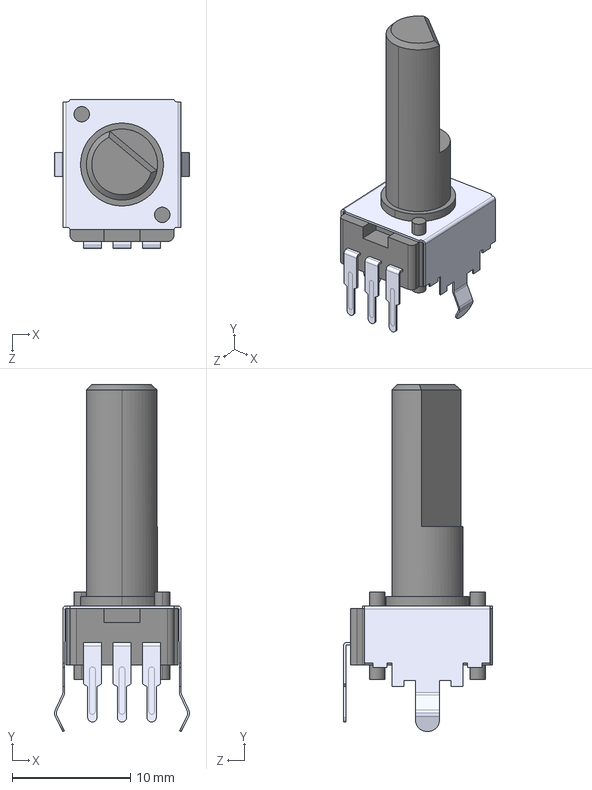
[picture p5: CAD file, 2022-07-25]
Schematic_PCB/Music_Visualizer/Project_Library/PTV09A_Pot_Vertical/PTV09A-4225F-B104.step
11.4 x 29.3 x 12.6 mm

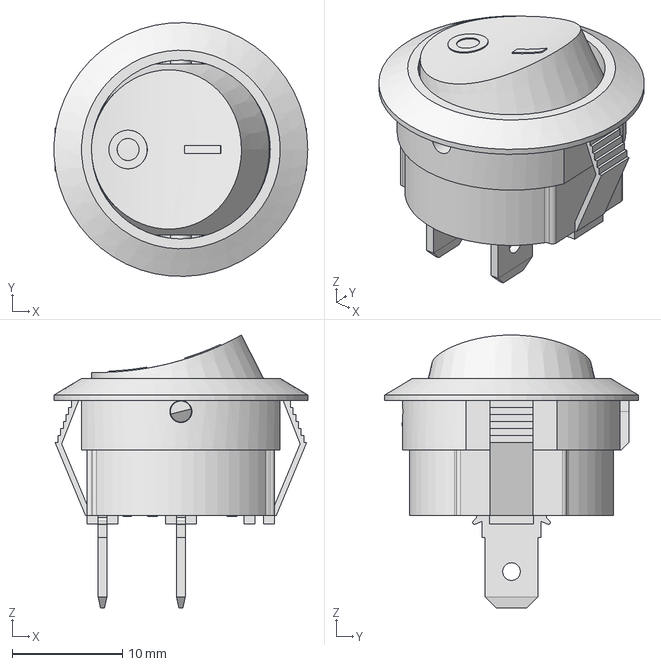
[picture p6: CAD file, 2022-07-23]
Schematic_PCB/Music_Visualizer/Project_Library/PW_On_Off_Switch/RR511D1121.step
23.0 x 23.0 x 24.7 mm

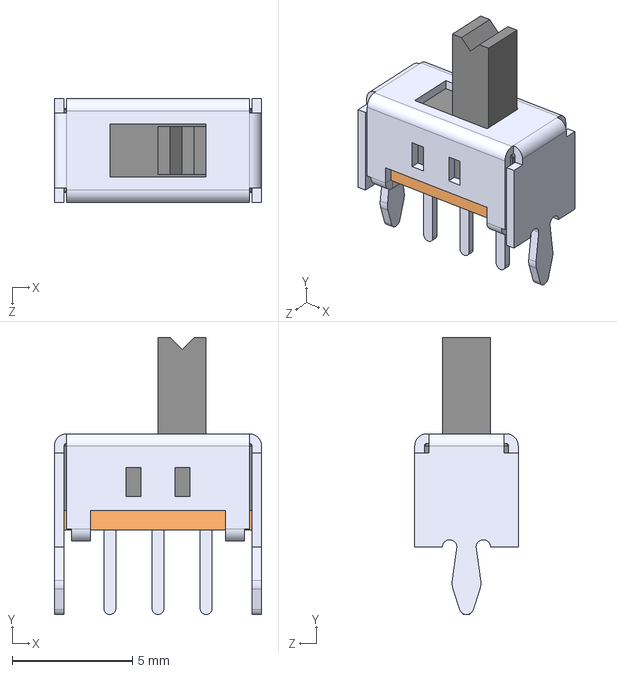
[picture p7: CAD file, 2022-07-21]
Schematic_PCB/Music_Visualizer/Project_Library/Slide_Switch/OS102011MS2QN1.step
8.60 x 11.5 x 4.30 mm

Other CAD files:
Schematic_PCB/Music_Visualizer/Project_Library/Coloured_LEDs/LED D5 - Yellow_cutted.step
Schematic_PCB/Music_Visualizer/Project_Library/Coloured_LEDs/LED D5 - Blue_cutted.step

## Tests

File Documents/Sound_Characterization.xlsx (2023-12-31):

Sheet: A to dB
A | Db
1 | 0
0.9 | -0.9151498112
0.8 | -1.93820026
0.7 | -3.0980392
0.6 | -4.436974992
0.5 | -6.020599913
0.4 | -7.958800173
0.3 | -10.45757491
0.2 | -13.97940009
0.1 | -20
0.09 | -20.91514981
0.08 | -21.93820026
0.07 | -23.0980392
0.06 | -24.43697499
0.05 | -26.02059991
0.04 | -27.95880017
0.03 | -30.45757491
0.02 | -33.97940009
0.01 | -40
0.001 | -60
0.0001 | -80

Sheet: Volume Ranges
Player Volume | Peak-Peak Voltage (Speaker Volume = 42) | Peak-Peak Voltage (Speaker Volume = 100) | Voltage Amplitude (Speaker Volume = 42) | Voltage amplitdue (Speaker Volume = 100)
0 | 0 | 0 | 0 | 0
10 | 0.033 | 0.165 | 0.0165 | 0.0825
20 | 0.065 | 0.316 | 0.0325 | 0.158
30 | 0.099 | 0.466 | 0.0495 | 0.233
40 | 0.133 | 0.619 | 0.0665 | 0.3095
50 | 0.167 | 0.768 | 0.0835 | 0.384
60 | 0.209 | 0.983 | 0.1045 | 0.4915
70 | 0.246 | 1.144 | 0.123 | 0.572
80 | 0.28 | 1.3 | 0.14 | 0.65
90 | 0.315 | 1.457 | 0.1575 | 0.7285
100 | 0.345 | 1.6 | 0.1725 | 0.8
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

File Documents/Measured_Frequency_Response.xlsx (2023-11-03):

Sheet: Octave
Filter | LC/2 | Vi (p-p) | Vo(p-p) | % | Magnitude(dB) | Lc | Vi (p-p) | Vo(p-p) | % | Magnitude(dB) | Center | Vi (p-p) | Vo(p-p) | % | Magnitude(dB) | Rc | Vi (p-p) | Vo(p-p) | % | Magnitude(dB) | Rc*2 | Vi (p-p) | Vo(p-p) | % | Magnitude(dB)
Bass | 30 | 2.002 | 0.146 | 7.293 | -22.742 | 60 | 2.002 | 1.422 | 71.029 | -2.971 | 185 | 2.002 | 2.071 | 103.447 | 0.294 | 250 | 2.002 | 1.464 | 73.127 | -2.718 | 500 | 1.98 | 0.146 | 7.374 | -22.646
Low-Midrange | 125 | 2.002 | 0.063 | 3.147 | -30.042 | 250 | 1.98 | 1.255 | 63.384 | -3.960 | 375 | 1.98 | 1.778 | 89.798 | -0.935 | 500 | 1.98 | 1.38 | 69.697 | -3.136 | 1000 | 1.959 | 0.063 | 3.216 | -29.854
Midrange | 250 | 1.98 | 0.105 | 5.303 | -25.510 | 500 | 1.98 | 0.816 | 41.212 | -7.700 | 1250 | 1.959 | 0.983 | 50.179 | -5.990 | 2000 | 1.938 | 0.774 | 39.938 | -7.972 | 4000 | 1.917 | 0.105 | 5.477 | -25.229
Upper-Mid | 1000 | 1.959 | 0.063 | 3.216 | -29.854 | 2000 | 1.938 | 1.485 | 76.625 | -2.313 | 3000 | 1.917 | 1.82 | 94.940 | -0.451 | 4000 | 1.917 | 1.276 | 66.562 | -3.535 | 8000 | 1.896 | 0.063 | 3.323 | -29.570
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

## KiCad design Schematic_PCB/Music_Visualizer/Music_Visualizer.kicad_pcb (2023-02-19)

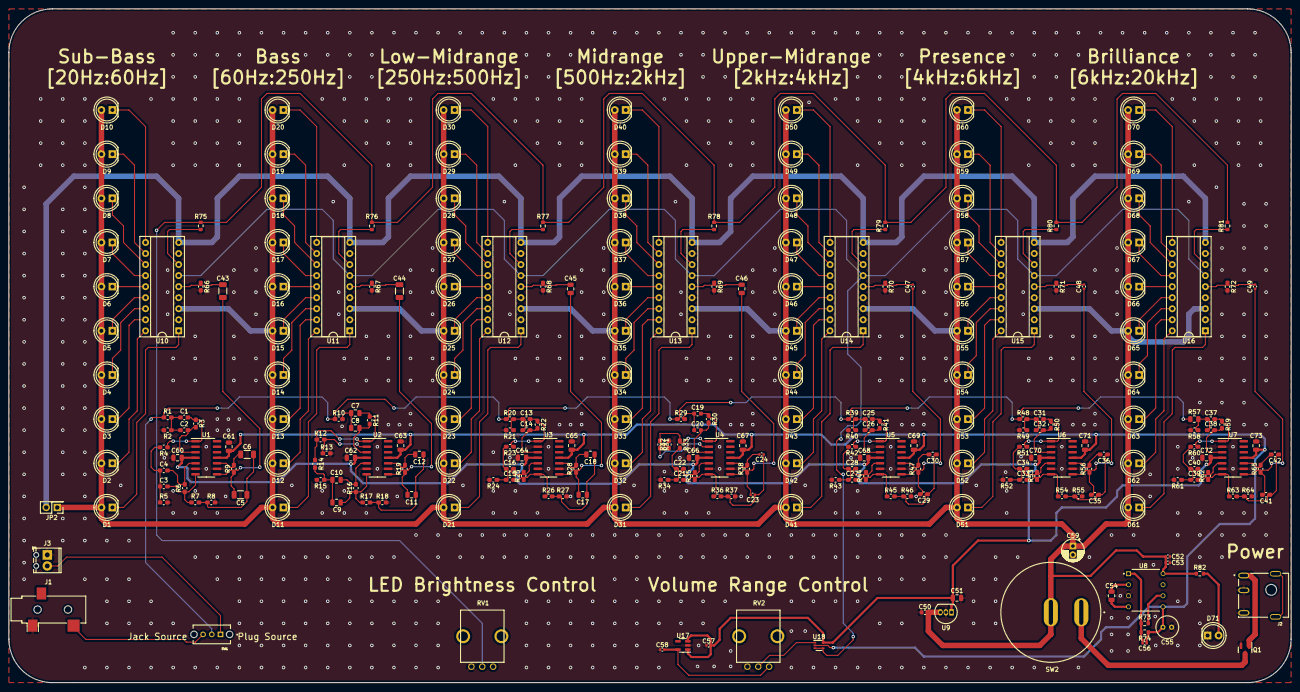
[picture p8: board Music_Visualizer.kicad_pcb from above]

Board: 2 copper layers, 295.0 x 155.0 mm, 253 parts (0 on the bottom side), 169 nets.

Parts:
C1, C2: 47n; C_0603_1608Metric_Pad1.08x0.95mm_HandSolder
C3, C4: 27n; C_0603_1608Metric_Pad1.08x0.95mm_HandSolder
C5, C6: 75n; C_1206_3216Metric
C7, C8: 13n; C_0805_2012Metric
C9, C10: 6.8n; C_0805_2012Metric
C11, C12: 24n; C_0805_2012Metric
C13, C14: 4.7n; C_0603_1608Metric_Pad1.08x0.95mm_HandSolder
C15, C16: 3.3n; C_0603_1608Metric_Pad1.08x0.95mm_HandSolder
C17, C18: 6.2n; C_0805_2012Metric
C19, C20: 1.6n; C_0603_1608Metric
C21, C22, C25, C26, C27, C28, C29, C30, C31, C32, C33, C34, C35, C36, C37, C38, C39, C40, C41, C42: 1n; C_0603_1608Metric_Pad1.08x0.95mm_HandSolder
C23, C24: 3n; C_0402_1005Metric
C43, C44: 100u; C_1206_3216Metric
C45, C46, C54: 10u; C_0805_2012Metric
C47, C48, C49, C52, C53, C57, C58: 1u; C_0402_1005Metric
C50: 0.33uF; C_0603_1608Metric
C51, C60, C61, C62, C63, C64, C65, C66, C67, C68, C69, C70, C71, C72, C73: 0.1uF; C_0805_2012Metric
C55: 100u; C_Radial_D5.0mm_H5.0mm_P2.00mm
C56: 0.002u; C_0402_1005Metric
C59: 10u; CP_Radial_D5.0mm_P2.00mm
D1, D2, D3, D4, D5, D6, D7, D8, D9, D10, D11, D12, D13, D14, D15, D16, D17, D18, D19, D20, D21, D22, D23, D24, D25, D26, D27, D28, D29, D30, D31, D32, D33, D34, D35, D36, D37, D38, D39, D40, D41, D42, D43, D44, D45, D46, D47, D48, D49, D50, D51, D52, D53, D54, D55, D56, D57, D58, D59, D60, D61, D62, D63, D64, D65, D66, D67, D68, D69, D70, D71: LED; LED_D5.0mm
J1: AudioJack3; Jack_3.5mm_CUI_SJ-3523-SMT_Horizontal
J2: PJ-079BH; CUI_PJ-079BH
J3: Screw_Terminal_01x02; TerminalBlock_Phoenix_MPT-0,5-2-2.54_1x02_P2.54mm_Horizontal
JP2: Jumper_2_Open; PinHeader_2x01_P2.54mm_Vertical
Q1: DMP2123LQ-7; SOT-23
R1: 84.5k; C_0603_1608Metric_Pad1.08x0.95mm_HandSolder
R2, R41, R50: 160k; C_0603_1608Metric_Pad1.08x0.95mm_HandSolder
R3: 169k; C_0603_1608Metric_Pad1.08x0.95mm_HandSolder
R4, R11, R65: 90.9k; C_0603_1608Metric_Pad1.08x0.95mm_HandSolder
R5, R62: 37.4k; C_0603_1608Metric_Pad1.08x0.95mm_HandSolder
R6: 402k; C_0603_1608Metric_Pad1.08x0.95mm_HandSolder
R7: 86.6k; C_0603_1608Metric_Pad1.08x0.95mm_HandSolder
R8: 35.7k; C_0603_1608Metric_Pad1.08x0.95mm_HandSolder
R9: 390k; C_0603_1608Metric_Pad1.08x0.95mm_HandSolder
R10: 110k; C_0603_1608Metric_Pad1.08x0.95mm_HandSolder
R12: 162k; C_0603_1608Metric_Pad1.08x0.95mm_HandSolder
R13: 118k; C_0603_1608Metric_Pad1.08x0.95mm_HandSolder
R14: 63.4k; C_0603_1608Metric_Pad1.08x0.95mm_HandSolder
R15: 62k; C_0603_1608Metric_Pad1.08x0.95mm_HandSolder
R16: 309k; C_0603_1608Metric_Pad1.08x0.95mm_HandSolder
R17: 68k; C_0603_1608Metric_Pad1.08x0.95mm_HandSolder
R18, R31, R36, R51: 66.5k; C_0603_1608Metric_Pad1.08x0.95mm_HandSolder
R19: 332k; C_0603_1608Metric_Pad1.08x0.95mm_HandSolder
R20: 137k; C_0603_1608Metric_Pad1.08x0.95mm_HandSolder
R21: 45.3k; C_0603_1608Metric_Pad1.08x0.95mm_HandSolder
R22, R35, R53: 270k; C_0603_1608Metric_Pad1.08x0.95mm_HandSolder
R23: 143k; C_0603_1608Metric_Pad1.08x0.95mm_HandSolder
R24: 19.1k; C_0603_1608Metric_Pad1.08x0.95mm_HandSolder
R25: 590k; C_0603_1608Metric_Pad1.08x0.95mm_HandSolder
R26: 140k; C_0603_1608Metric_Pad1.08x0.95mm_HandSolder
R27: 18.7k; C_0603_1608Metric_Pad1.08x0.95mm_HandSolder
R28: 576k; C_0603_1608Metric_Pad1.08x0.95mm_HandSolder
R29, R30: 100k; C_0603_1608Metric_Pad1.08x0.95mm_HandSolder
R32: 33.2k; C_0603_1608Metric_Pad1.08x0.95mm_HandSolder
R33: 56k; C_0603_1608Metric_Pad1.08x0.95mm_HandSolder
R34, R58: 48.7k; C_0603_1608Metric_Pad1.08x0.95mm_HandSolder
R37: 57.6k; C_0603_1608Metric_Pad1.08x0.95mm_HandSolder
R38: 324k; C_0603_1608Metric_Pad1.08x0.95mm_HandSolder
R39, R48: 78.7k; C_0603_1608Metric_Pad1.08x0.95mm_HandSolder
R40: 26.7k; C_0603_1608Metric_Pad1.08x0.95mm_HandSolder
R42: 59k; C_0603_1608Metric_Pad1.08x0.95mm_HandSolder
R43: 7.87k; C_0603_1608Metric_Pad1.08x0.95mm_HandSolder
R44: 243k; C_0603_1608Metric_Pad1.08x0.95mm_HandSolder
R45: 107k; C_0603_1608Metric_Pad1.08x0.95mm_HandSolder
R46: 14.7k; C_0603_1608Metric_Pad1.08x0.95mm_HandSolder
R47: 453k; C_0603_1608Metric_Pad1.08x0.95mm_HandSolder
R49: 7.32k; C_0603_1608Metric_Pad1.08x0.95mm_HandSolder
R52: 2.87k; C_0603_1608Metric_Pad1.08x0.95mm_HandSolder
R54: 95.3k; C_0603_1608Metric_Pad1.08x0.95mm_HandSolder
R55: 4.02k; C_0603_1608Metric_Pad1.08x0.95mm_HandSolder
R56: 383k; C_0603_1608Metric_Pad1.08x0.95mm_HandSolder
R57: 11.5k; R_0805_2012Metric
R59: 22.6k; C_0603_1608Metric_Pad1.08x0.95mm_HandSolder
R60: 8.06k; C_0603_1608Metric_Pad1.08x0.95mm_HandSolder
R61: 4.32k; C_0603_1608Metric_Pad1.08x0.95mm_HandSolder
R63: 19.6k; C_0603_1608Metric_Pad1.08x0.95mm_HandSolder
R64: 10.7k; C_0603_1608Metric_Pad1.08x0.95mm_HandSolder
R66, R67, R68, R69, R70, R71, R72: 1k; C_0603_1608Metric_Pad1.08x0.95mm_HandSolder
R73: 20k; R_0603_1608Metric
R74: 102k; R_0603_1608Metric
R75, R76, R77, R78, R79, R80, R81: 680; R_0603_1608Metric
R82: 330; R_0603_1608Metric
RV1: 10k_LED_Brightness_Pot; PTV09
RV2: 5k_Rhi_Adjuster; PTV09
SW1: SW_SPDT; SW_OS102011MS2QN1
SW2: SW_SPST; E-SWITCH_RR511D1121
U1, U2, U3, U4, U5, U6, U7: LM324; SOIC-14_3.9x8.7mm_P1.27mm
U8: LT1054; DIP794W45P254L959H508Q8
U9: MC78L05_TO92; TO-92_Inline
U10, U11, U12, U13, U14, U15, U16: LM3915N-1; DIP-18_W7.62mm_Socket
U17: NCP161ASN350T1G; SOT-23-5
U18: NCS333ASQ3T2G; SOT-353_SC-70-5

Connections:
+5V: C51.1, C57.1, C60.2, C62.2, C64.2, C66.2, C68.2, C70.2, C72.2, U1.4 (V+), U2.4 (V+), U3.4 (V+), U4.4 (V+), U5.4 (V+), U6.4 (V+), U7.4 (V+), U9.1 (VO), U17.1 (IN), U17.3 (EN), U18.5 (V+)
+9V: C50.1, C52.1, C53.1, C59.1, D1.2 (A), D2.2 (A), D3.2 (A), D4.2 (A), D5.2 (A), D6.2 (A), D7.2 (A), D8.2 (A), D9.2 (A), D10.2 (A), D11.2 (A), D12.2 (A), D13.2 (A), D14.2 (A), D15.2 (A), D16.2 (A), D17.2 (A), D18.2 (A), D19.2 (A), D20.2 (A), D21.2 (A), D22.2 (A), D23.2 (A), D24.2 (A), D25.2 (A), D26.2 (A), D27.2 (A), D28.2 (A), D29.2 (A), D30.2 (A), D31.2 (A), D32.2 (A), D33.2 (A), D34.2 (A), D35.2 (A), D36.2 (A), D37.2 (A), D38.2 (A), D39.2 (A), D40.2 (A), D41.2 (A), D42.2 (A), D43.2 (A), D44.2 (A), D45.2 (A), D46.2 (A), D47.2 (A), D48.2 (A), D49.2 (A), D50.2 (A), D51.2 (A), D52.2 (A), D53.2 (A), D54.2 (A), D55.2 (A), D56.2 (A), D57.2 (A), D58.2 (A), D59.2 (A), D60.2 (A), D61.2 (A), D62.2 (A), D63.2 (A), D64.2 (A), D65.2 (A), D66.2 (A), D67.2 (A), D68.2 (A), D69.2 (A), D70.2 (A), JP2.1 (A), R82.1, SW2.2 (B), U8.8 (V+), U9.3 (VI), U10.3 (V+), U11.3 (V+), U12.3 (V+), U13.3 (V+), U14.3 (V+), U15.3 (V+), U16.3 (V+)
-5V: C55.1, C56.1, C61.1, C63.1, C65.1, C67.1, C69.1, C71.1, C73.1, R74.1, U1.11 (V-), U2.11 (V-), U3.11 (V-), U4.11 (V-), U5.11 (V-), U6.11 (V-), U7.11 (V-), U8.5 (-VOUT), U18.2 (V-)
/Power/Power: J2.1, Q1.1 (D)
/Vsig_female: J1.T, SW1.3 (C)
/Vsig_male: J3.2, SW1.1 (A)
GND: C50.2, C51.2, C52.2, C53.2, C55.2, C57.2, C58.2, C59.2, C60.1, C61.2, C62.1, C63.2, C64.1, C65.2, C66.1, C67.2, C68.1, C69.2, C70.1, C71.2, C72.1, C73.2, D71.1 (K), J1.S, J2.2, J2.3, J3.1, Q1.2 (G), R2.2, R5.2, R8.2, R13.2, R15.2, R18.2, R21.2, R24.2, R27.2, R32.2, R34.2, R37.2, R40.2, R43.2, R46.2, R49.2, R52.2, R55.2, R58.2, R61.2, R64.2, R66.2, R67.2, R68.2, R69.2, R70.2, R71.2, R72.2, RV1.1, RV2.1, U1.2 (-), U1.6 (-), U1.9 (-), U2.6 (-), U2.9 (-), U3.2 (-), U3.6 (-), U3.9 (-), U4.6 (-), U4.9 (-), U5.2 (-), U5.6 (-), U5.9 (-), U6.2 (-), U6.6 (-), U6.9 (-), U7.2 (-), U7.6 (-), U7.9 (-), U8.3 (GND), U9.2 (GND), U10.2 (V-), U10.4 (RLO), U10.8 (REF_ADJ), U11.2 (V-), U11.4 (RLO), U11.8 (REF_ADJ), U12.2 (V-), U12.4 (RLO), U12.8 (REF_ADJ), U13.2 (V-), U13.4 (RLO), U13.8 (REF_ADJ), U14.2 (V-), U14.4 (RLO), U14.8 (REF_ADJ), U15.2 (V-), U15.4 (RLO), U15.8 (REF_ADJ), U16.2 (V-), U16.4 (RLO), U16.8 (REF_ADJ), U17.2 (GND)
LED_Brightness_Control: R75.2, R76.2, R77.2, R78.2, R79.2, R80.2, R81.2, RV1.2
Mode: JP2.2 (B), U10.9 (MODE), U11.9 (MODE), U12.9 (MODE), U13.9 (MODE), U14.9 (MODE), U15.9 (MODE), U16.9 (MODE)
unnamed: C1.1, C2.1, R1.2, R2.1
unnamed: C1.2, R3.1, R4.1, U1.1
unnamed: C2.2, R3.2, U1.3 (+)
unnamed: C3.1, C4.1, R4.2, R5.1
unnamed: C3.2, R6.1, R7.1, U1.7
unnamed: C4.2, R6.2, U1.5 (+)
unnamed: C5.1, C6.1, R7.2, R8.1
unnamed: C6.2, R9.2, U1.10 (+)
unnamed: C7.1, C8.1, R10.2
unnamed: C7.2, R11.1, R12.1, R14.1, U2.1
unnamed: C8.2, R11.2, U2.3 (+)
unnamed: C9.2, R16.1, R17.1, U2.7
unnamed: C9.1, C10.1, R14.2, R15.1
unnamed: C10.2, R16.2, U2.5 (+)
unnamed: C11.1, C12.1, R17.2, R18.1
unnamed: C11.2, C44.1, R19.1, U2.8
unnamed: C12.2, R19.2, U2.10 (+)
unnamed: C13.1, C14.1, R20.2, R21.1
unnamed: C13.2, R22.1, R23.1, U3.1
unnamed: C14.2, R22.2, U3.3 (+)
unnamed: C15.1, C16.1, R23.2, R24.1
unnamed: C15.2, R25.1, R26.1, U3.7
unnamed: C16.2, R25.2, U3.5 (+)
unnamed: C17.1, C18.1, R26.2, R27.1
unnamed: C17.2, C45.1, R28.1, U3.8
unnamed: C18.2, R28.2, U3.10 (+)
unnamed: C19.1, C20.1, R29.2
unnamed: C19.2, R30.1, R31.1, R33.1, U4.1
unnamed: C20.2, R30.2, U4.3 (+)
unnamed: C21.1, C22.1, R33.2, R34.1
unnamed: C21.2, R35.1, R36.1, U4.7
unnamed: C22.2, R35.2, U4.5 (+)
unnamed: C23.1, C24.1, R36.2, R37.1
unnamed: C23.2, C46.1, R38.1, U4.8
unnamed: C24.2, R38.2, U4.10 (+)
unnamed: C25.1, C26.1, R39.2, R40.1
unnamed: C25.2, R41.1, R42.1, U5.1
unnamed: C26.2, R41.2, U5.3 (+)
unnamed: C27.1, C28.1, R42.2, R43.1
unnamed: C27.2, R44.1, R45.1, U5.7
unnamed: C28.2, R44.2, U5.5 (+)
unnamed: C29.1, C30.1, R45.2, R46.1
unnamed: C29.2, C47.1, R47.1, U5.8
unnamed: C30.2, R47.2, U5.10 (+)
unnamed: C31.1, C32.1, R48.2, R49.1
unnamed: C31.2, R50.1, R51.1, U6.1
unnamed: C32.2, R50.2, U6.3 (+)
unnamed: C33.1, C34.1, R51.2, R52.1
unnamed: C33.2, R53.1, R54.1, U6.7
unnamed: C34.2, R53.2, U6.5 (+)
unnamed: C35.1, C36.1, R54.2, R55.1
unnamed: C35.2, C48.1, R56.1, U6.8
unnamed: C36.2, R56.2, U6.10 (+)
unnamed: C37.1, C38.1, R57.2, R58.1
unnamed: C37.2, R59.1, R60.1, U7.1
unnamed: C38.2, R59.2, U7.3 (+)
unnamed: C39.1, C40.1, R60.2, R61.1
unnamed: C39.2, R62.1, R63.1, U7.7
unnamed: C40.2, R62.2, U7.5 (+)
unnamed: C41.1, C42.1, R63.2, R64.1
unnamed: C41.2, C49.1, R65.1, U7.8
unnamed: C42.2, R65.2, U7.10 (+)
unnamed: C5.2, C43.1, R9.1, U1.8
unnamed: C54.1, U8.2 (CAP+)
unnamed: C54.2, U8.4 (CAP-)
unnamed: C56.2, R73.1, R74.2, U8.1 (FB/SHDN)
unnamed: C58.1, RV2.3, U17.5 (OUT)
unnamed: D1.1 (K), U10.1 (LED1_K)
unnamed: D2.1 (K), U10.18 (LED2_K)
unnamed: D3.1 (K), U10.17 (LED3_K)
unnamed: D4.1 (K), U10.16 (LED4_K)
unnamed: D5.1 (K), U10.15 (LED5_K)
unnamed: D6.1 (K), U10.14 (LED6_K)
unnamed: D7.1 (K), U10.13 (LED7_K)
unnamed: D8.1 (K), U10.12 (LED8_K)
unnamed: D9.1 (K), U10.11 (LED9_K)
unnamed: D10.1 (K), U10.10 (LED10_K)
unnamed: D11.1 (K), U11.1 (LED1_K)
unnamed: D12.1 (K), U11.18 (LED2_K)
unnamed: D13.1 (K), U11.17 (LED3_K)
unnamed: D14.1 (K), U11.16 (LED4_K)
unnamed: D15.1 (K), U11.15 (LED5_K)
unnamed: D16.1 (K), U11.14 (LED6_K)
unnamed: D17.1 (K), U11.13 (LED7_K)
unnamed: D18.1 (K), U11.12 (LED8_K)
unnamed: D19.1 (K), U11.11 (LED9_K)
unnamed: D20.1 (K), U11.10 (LED10_K)
unnamed: D21.1 (K), U12.1 (LED1_K)
unnamed: D22.1 (K), U12.18 (LED2_K)
unnamed: D23.1 (K), U12.17 (LED3_K)
unnamed: D24.1 (K), U12.16 (LED4_K)
unnamed: D25.1 (K), U12.15 (LED5_K)
unnamed: D26.1 (K), U12.14 (LED6_K)
unnamed: D27.1 (K), U12.13 (LED7_K)
unnamed: D28.1 (K), U12.12 (LED8_K)
unnamed: D29.1 (K), U12.11 (LED9_K)
unnamed: D30.1 (K), U12.10 (LED10_K)
unnamed: D31.1 (K), U13.1 (LED1_K)
unnamed: D32.1 (K), U13.18 (LED2_K)
unnamed: D33.1 (K), U13.17 (LED3_K)
unnamed: D34.1 (K), U13.16 (LED4_K)
unnamed: D35.1 (K), U13.15 (LED5_K)
unnamed: D36.1 (K), U13.14 (LED6_K)
unnamed: D37.1 (K), U13.13 (LED7_K)
unnamed: D38.1 (K), U13.12 (LED8_K)
unnamed: D39.1 (K), U13.11 (LED9_K)
unnamed: D40.1 (K), U13.10 (LED10_K)
unnamed: D41.1 (K), U14.1 (LED1_K)
unnamed: D42.1 (K), U14.18 (LED2_K)
unnamed: D43.1 (K), U14.17 (LED3_K)
unnamed: D44.1 (K), U14.16 (LED4_K)
unnamed: D45.1 (K), U14.15 (LED5_K)
unnamed: D46.1 (K), U14.14 (LED6_K)
unnamed: D47.1 (K), U14.13 (LED7_K)
unnamed: D48.1 (K), U14.12 (LED8_K)
unnamed: D49.1 (K), U14.11 (LED9_K)
unnamed: D50.1 (K), U14.10 (LED10_K)
unnamed: D51.1 (K), U15.1 (LED1_K)
unnamed: D52.1 (K), U15.18 (LED2_K)
unnamed: D53.1 (K), U15.17 (LED3_K)
unnamed: D54.1 (K), U15.16 (LED4_K)
unnamed: D55.1 (K), U15.15 (LED5_K)
unnamed: D56.1 (K), U15.14 (LED6_K)
unnamed: D57.1 (K), U15.13 (LED7_K)
unnamed: D58.1 (K), U15.12 (LED8_K)
unnamed: D59.1 (K), U15.11 (LED9_K)
unnamed: D60.1 (K), U15.10 (LED10_K)
unnamed: D61.1 (K), U16.1 (LED1_K)
unnamed: D62.1 (K), U16.18 (LED2_K)
unnamed: D63.1 (K), U16.17 (LED3_K)
unnamed: D64.1 (K), U16.16 (LED4_K)
unnamed: D65.1 (K), U16.15 (LED5_K)
unnamed: D66.1 (K), U16.14 (LED6_K)
unnamed: D67.1 (K), U16.13 (LED7_K)
unnamed: D68.1 (K), U16.12 (LED8_K)
unnamed: D69.1 (K), U16.11 (LED9_K)
unnamed: D70.1 (K), U16.10 (LED10_K)
unnamed: D71.2 (A), R82.2
unnamed: J2.S1 (SHIELD), J2.S2 (SHIELD)
unnamed: Q1.3 (S), SW2.1 (A)
unnamed: R12.2, R13.1, U2.2 (-)
unnamed: R31.2, R32.1, U4.2 (-)
unnamed: R73.2, U8.6 (VREF)
unnamed: R75.1, U10.7 (REF_OUT)
unnamed: R76.1, U11.7 (REF_OUT)
unnamed: R77.1, U12.7 (REF_OUT)
unnamed: R78.1, U13.7 (REF_OUT)
unnamed: R79.1, U14.7 (REF_OUT)
unnamed: R80.1, U15.7 (REF_OUT)
unnamed: R81.1, U16.7 (REF_OUT)
unnamed: RV2.2, U18.1 (+)
Rhi_Value: U10.6 (RHI), U11.6 (RHI), U12.6 (RHI), U13.6 (RHI), U14.6 (RHI), U15.6 (RHI), U16.6 (RHI), U18.3 (-), U18.4
VBass: C44.2, R67.1, U11.5 (SIG)
VBrilliance: C49.2, R72.1, U16.5 (SIG)
VLowerMidrange: C45.2, R68.1, U12.5 (SIG)
VMidrange: C46.2, R69.1, U13.5 (SIG)
VPresence: C48.2, R71.1, U15.5 (SIG)
VSubBass: C43.2, R66.1, U10.5 (SIG)
VUpperMidrange: C47.2, R70.1, U14.5 (SIG)
Vsig: R1.1, R10.1, R20.1, R29.1, R39.1, R48.1, R57.1, SW1.2 (B)

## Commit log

2022-04-17 Add active Butterworth filter desgins from Sub-Bass, Bass, Low-Midrange, Midrange, Upper-Midrange, Presence, and Brilliance frequency spectrums
    [FrequencyInformation.xlsx]
2022-04-19 Add Compatoro-LED volume ladder schematic, and to the Frequency information spreadsheet - voltages of aux cable at different volumes and sheet showing how volume division will be done
    [FrequencyInformation.xlsx]
2022-04-20 Improved Sub-bass filter from a 4th to 6th order filter, and corrected passband of Bass filter
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2022-05-15 Corrected and organized spectrum filters and finalized design of negative power source
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2022-05-22 Finalized and sourced Resistor values for all filters
    [BOM.xlsx]
2022-05-22 Finalized and sourced Capacitor values for all filters
    [BOM.xlsx]
2022-05-26 Replaced through-hole resistors and capacitors with SMD types, all resisotrs of Case Code (mm) 0603, most caps are Case Code (mm) 0603, a few are 1005, 1608, 2012 and 3216
    [BOM.xlsx, Materials.xlsx]
2022-05-26 Made design to control LED's of all LM3915 ic's from a single potentiometer. Drawback - reference voltage between pin 7 and pin 8 will be between 20mV and 764mV depending on the potentiometer value, 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
2022-06-01 LED Driver IC excel file shows result of varying resistance between pin Ref and ground and grounding pin Adj. Doing so with one LM3915 IC was simulated in Base Circuit version 2, doing so with all 7 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
    [LED Driver IC.xlsx]
2022-06-08 Added Case code (mm) and datasheet links for all resistors and capacitors in Sub-bass and Bass filters in the BOM excel file
    [BOM.xlsx]
2022-06-08 Started making schematic of project in KiCad, currently finished drafting the sub-Bass filter with correct footprints
    [Music_Visualizer.kicad_pcb, Music_Visualizer.kicad_sch]
2022-06-08 Added Case code (mm) and datasheet links for all resistors and capacitors in the remaining filters
    [BOM.xlsx]
2022-06-08 Added passive components of all filters on one sheet it Bom, component number reflects its ordering in the schematic
    [BOM.xlsx]
2022-06-08 Added all filters with proper footprints to KiCad Schematic
    [Music_Visualizer.kicad_sch]
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2022-06-23 Component values and outputs for Negative Voltage Multiplier 555 timer
    [NegativeVoltageMuliplier555.xlsx]
2022-06-23 Corrected polarity of C4 and C5, added voltage node labels
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2022-06-23 Sourced male and female audio inputs, selector switch and power button
    [BOM.xlsx]
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2022-06-30 Calculate maximum current being outputted by each Spectrum filter and each stage within them
    [MaxIoOfEachFilterStage.xlsx]
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2022-07-19 Updated Bom, Full Visualizer Circuit, and Circuit for establishing -5 volts
    [BOM.xlsx]
2022-07-21 Tested feasibility of using KiCad to simulate circuit to ensure correct operation, not realiable, will use CircuitMaker as I am faster with that
    [lm741.dsn, lmx24_lm2902.dsn, test.kicad_pcb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]
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2022-07-21 Completed and annotated Spectrum filters and power circuitry, and updated BOM
    [BOM.xlsx, Music_Visualizer.kicad_sch, Power.kicad_sch]
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2022-07-23 Sourced on_off switch and added on_off switch/indicator circuit
    [BOM.xlsx, Led_Driver.kicad_sch, Music_Visualizer.kicad_sch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]
2022-07-25 Got 3D models for all parts, corrected signal voltage to each driver and made outline of PCB
    [CUI_DEVICES_PJ-070BH-SMT-TR.step, CUI_DEVICES_PJ-079BH.step, Led_Driver.kicad_sch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]
2022-07-25 Formated LEDs, LED drivers and filters in PCB editor
    [Music_Visualizer.kicad_pcb]
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2022-07-30 Both parts ar PVT09A 5K ohms, corrected footprint terminal labels
    [BOM.xlsx, Led_Driver.kicad_sch, Music_Visualizer.kicad_pcb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]
2022-08-04 Fully connected LEDs and driver ICs to 9V
    [Music_Visualizer.kicad_pcb]
2022-08-25 Table and chart of trace width vs current
    [Trace width vs current.xlsx]
2022-08-25 Added 10 uF polarized smoothing capacitors to LED driver ciruit
    [BOM.xlsx, Led_Driver.kicad_sch, Music_Visualizer.kicad_pcb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]
2022-08-27 Changed Grid 1 & 2 to 50 mils and 10 mils respectively, and deleted all traces
    [Music_Visualizer.kicad_pcb]
2022-08-28 Aligned all subcircuits, routed 9V and power, started routing LEDS
    [Music_Visualizer.kicad_pcb]
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2022-08-30 Added 7th LM324 Quad-op-amp IC to Filter array, updated numbering on all other ICs
    [Led_Driver.kicad_sch, Music_Visualizer.kicad_pcb, Music_Visualizer.kicad_sch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]
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2022-09-20 Added ground pour to top and bottom layers
    [Music_Visualizer.kicad_pcb]
2022-09-20 Found new way to rout internal filter stages, completed Sub-Bass filter, allows grounds to be connected and leaves spaces +/- 5V power
    [Music_Visualizer.kicad_pcb]
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2022-09-22 Added screw port terminal block to connect male audio jack, traceed audio input and header, all nets have now been traced
    [BOM.xlsx, Music_Visualizer.kicad_pcb, Music_Visualizer.kicad_sch]
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2022-10-13 Added 0.1uF decoupling capacitors to the op-amps on the schematic and placed and traced on the PCB
    [Music_Visualizer.kicad_pcb, Music_Visualizer.kicad_sch]
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2022-10-15 Added pmos for reverse voltage protection
    [Music_Visualizer.kicad_pcb, Music_Visualizer.kicad_sch, Power.kicad_sch]
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2022-10-19 Started sourcing parts from digikey, got to part 15, corrected mistakes as I go along
    [Music_Visualizer.csv, Music_Visualizer.kicad_pcb, Music_Visualizer.kicad_sch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]
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2022-10-25 Made a xlsx version of the BOM, added some more stitching vias to the PCB, replaced audio jack in the BOM from a TH to SMT
    [Music_Visualizer.kicad_pcb, Music_Visualizer_BOM.csv, Music_Visualizer_BOM.xlsx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]
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2023-02-10 Corrected LT1054 -5V power output label placement, identified which components are 0201 and corrected digi number and page of C-47,48,49,52,53,58 1u caps
    [Music_Visualizer.kicad_pcb, Music_Visualizer.kicad_sch, Music_Visualizer_BOM.xlsx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]
2023-02-19 Sourced 0603 replacements for 0201 components
    [Music_Visualizer_BOM.xlsx]
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2023-03-01 Changed 0603 footprint to hand solder version, and changed 0402 footprints to 0603 hand solder version
    [Led_Driver.kicad_sch, Music_Visualizer.kicad_sch, Power.kicad_sch]
2023-03-02 Corrected Resistor footprints from Capacitor_SMD to Resistor_SMD and created BOM
    [Led_Driver.kicad_sch, Music_Visualizer.csv, Music_Visualizer.kicad_sch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]
2023-03-15 Corrected Spectrum Filter mistakes
    In Kicad, op amp filters were connected as positive feedback, changed to negative feedback; corrected R5 and R8 values in FinalLowMidrange LTSpice file; corrected R2 and R3 in FinalUpperMidrange LTspice file; corrected R2 in FinalPresence LTSpice file; changed C39 and C40 in Kicad Brilliance Filter from 1nF to 820pF
    [Led_Driver.kicad_sch, Music_Visualizer.kicad_sch, Power.kicad_sch]
2023-03-16 Fixed filter op-amp connections in the PCB
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2023-08-04 Verified BOM correctness and availabity of parts
    [Music_Visualizer_BOM_Digikey_Final_V2.xlsx]
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2023-09-14 Compared soldered passsive components to their measured value, and calculated the amplitude of the audio voltage signal at 42 and 100 percent system power
    [FrequencyInformation.xlsx, Music_Visualizer_BOM_Digikey_Final_V2.xlsx]
2023-09-14 Added 4th op amp in each LM324 IC as a voltage follower (buffer) for each spectrum filter in the schematic
    [Led_Driver.kicad_sch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]
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2023-10-02 Updated Manufacturing files for the purpose of having JLC attach passive components to the PCB
    [Music_Visualizer-B_Cu.gbl, Music_Visualizer-B_Mask.gbs, Music_Visualizer-B_Paste.gbp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]
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2023-10-25 Re-oriented C55 (The 100uF capacitor) so that the positive terminal is connected to ground and the negative terminal is connected to -5V in the schematic and PCB layout
    [Power.kicad_sch]
2023-10-27 Used an emitter follower circuit to replace the unity voltage buffer in the Rhi control circuit
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2023-12-30 Create new subfolder in Simulated_Circuits, Power, and moved LT1054_Inverter_and_regulator and Reverse_Voltage_Protection to this folder
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2024-01-06 Moved DC power jack symbol from global library to project specific library
    [Power.kicad_sch]
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2024-01-06 Update README.md
    Add Generate Files for Fabrication, Current Issues and Acknowledgments
2024-01-09 Added 3D modles for blue, red and yellow 5mm cutted opaque LEDS and used their 3D models for the project
    [LED D5 - Blue_cutted.step, LED D5 - Red_cutted.step, LED D5 - Yellow_cutted.step]
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2024-01-23 Replaced voltage divider to Vrhi with a constant voltage source
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2024-01-23 Rearraged Power circuitry schematic and made the paper size custom: 180W x 250H
    [Led_Driver.kicad_sch, Music_Visualizer.kicad_sch, Power.kicad_sch]
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
